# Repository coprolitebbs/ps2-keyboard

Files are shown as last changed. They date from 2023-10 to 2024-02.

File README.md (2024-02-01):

# ps2-keyboard
Самодельная клавиатура с интерфейсом ps/2.
Собрана на Attiny2313A и сдвиговых регистрах 74HC595 и 74HC165.

Прошивка Attiny базируется на библиотеке [ps2dev](https://github.com/Harvie/ps2dev)

Простое описание данных для протокола [PS/2](https://marsohod.org/11-blog/57-ps2proto).

Если что-то не работает, попробуйте старую прошивку из моей же статьи на хабре:
https://habr.com/ru/articles/693784/
Например, эмулятор PS/2 клавиатуры для Спектрума, почему-то, не заводится с последней версией прошивки, но, завелся с версией из статьи.
Собирали на стриме здесь: https://www.youtube.com/watch?v=hVR3ve-gX_8

Прошивка компилируется средой Arduino IDE,

Прошивается с помощью progisp172 программатором через порт "РПрог" для программирования на плате клавиатуры,

Fuse-биты для Attiny2313A: 
Low: E2, High: DF, Ext: FF, Lock: FF

**Имейте ввиду, клавиатура не настраивается под ваш PC или контроллер автоматически,
придется играться с таймингами в исходнике.**

**Для PC используйте значения:**
```
 #define BYTEWAIT 1000
 #define CLK_FULL 40 
 #define CLK_HALF 20
 #define TIMEOUT 30
```

**Для работы с esp32 и библиотекой FabGL используйте**
```
 #define BYTEWAIT 500
 #define CLK_FULL 10 
 #define CLK_HALF 5
 #define TIMEOUT 50
```

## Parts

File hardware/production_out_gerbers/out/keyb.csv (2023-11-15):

Id | Designator | Footprint | Quantity | Designation | Supplier and ref
1 | SW23 | SW_PUSH_KEYB_6mm_H4.3mm | 1 | 9 (
2 | SW18 | SW_PUSH_KEYB_6mm_H4.3mm | 1 | 4 $ ;
3 | SW34 | SW_PUSH_KEYB_6mm_H4.3mm | 1 | + =
4 | SW68 | SW_PUSH_KEYB_6mm_H4.3mm | 1 | X Ч
5 | R11,R13,R10,R7,R8,R19,R20,R15,R14,R6,R18,R17,R12,R5,R9,R16 | R_Axial_DIN0204_L3.6mm_D1.6mm_P7.62mm_Horizontal | 16 | 220
6 | SW19 | SW_PUSH_KEYB_6mm_H4.3mm | 1 | 5 %
7 | SW20 | SW_PUSH_KEYB_6mm_H4.3mm | 1 | 6 ^ :
8 | SW76 | SW_PUSH_KEYB_6mm_H4.3mm | 1 | / ? .
9 | SW12 | SW_PUSH_KEYB_6mm_H4.3mm | 1 | Ф8
10 | SW82,SW78 | SW_PUSH_KEYB_6mm_H4.3mm | 2 | КТРЛ
11 | SW46 | SW_PUSH_KEYB_6mm_H4.3mm | 1 | Y Н
12 | SW67 | SW_PUSH_KEYB_6mm_H4.3mm | 1 | Z Я
13 | SW43 | SW_PUSH_KEYB_6mm_H4.3mm | 1 | ПЕЧАТЬ
14 | R2,R3 | R_Axial_DIN0204_L3.6mm_D1.6mm_P7.62mm_Horizontal | 2 | 1K
15 | SW70 | SW_PUSH_KEYB_6mm_H4.3mm | 1 | V М
16 | SW56 | SW_PUSH_KEYB_6mm_H4.3mm | 1 | S Ы
17 | SW72 | SW_PUSH_KEYB_6mm_H4.3mm | 1 | N Т
18 | SW14 | SW_PUSH_KEYB_6mm_H4.3mm | 1 | Ф10
19 | SW28 | SW_PUSH_KEYB_6mm_H4.3mm | 1 | ВПРАВО
20 | SW60 | SW_PUSH_KEYB_6mm_H4.3mm | 1 | H Р
21 | SW77 | SW_PUSH_KEYB_6mm_H4.3mm | 1 | RSHIFT
22 | SW73 | SW_PUSH_KEYB_6mm_H4.3mm | 1 | M Ь
23 | SW83 | SW_PUSH_KEYB_6mm_H4.3mm | 1 | ПАУЗА
24 | SW65 | SW_PUSH_KEYB_6mm_H4.3mm | 1 | ' Э"
25 | SW79,SW81 | SW_PUSH_KEYB_6mm_H4.3mm | 2 | АЛЬТ
26 | D1 | LED_D3.0mm | 1 | Св.1
27 | SW75 | SW_PUSH_KEYB_6mm_H4.3mm | 1 | > . Ю
28 | SW74 | SW_PUSH_KEYB_6mm_H4.3mm | 1 | < , Б
29 | SW36 | SW_PUSH_KEYB_6mm_H4.3mm | 1 | УДАЛ
30 | SW48 | SW_PUSH_KEYB_6mm_H4.3mm | 1 | I Ш
31 | SW55 | SW_PUSH_KEYB_6mm_H4.3mm | 1 | A Ф
32 | SW6 | SW_PUSH_KEYB_6mm_H4.3mm | 1 | ` ~ Ё
33 | SW30 | SW_PUSH_KEYB_6mm_H4.3mm | 1 | НАЗАД
34 | SW47 | SW_PUSH_KEYB_6mm_H4.3mm | 1 | U Г
35 | SW71 | SW_PUSH_KEYB_6mm_H4.3mm | 1 | B И
36 | J2 | PinSocket_2x03_P2.54mm_Vertical_ICSP | 1 | ICSP
37 | SW11 | SW_PUSH_KEYB_6mm_H4.3mm | 1 | Ф7
38 | SW64 | SW_PUSH_KEYB_6mm_H4.3mm | 1 | : ; Ж
39 | SW7 | SW_PUSH_KEYB_6mm_H4.3mm | 1 | 1 !
40 | SW26 | SW_PUSH_KEYB_6mm_H4.3mm | 1 | ВНИЗ
41 | SW15 | SW_PUSH_KEYB_6mm_H4.3mm | 1 | Ф11
42 | SW22 | SW_PUSH_KEYB_6mm_H4.3mm | 1 | 8 *
43 | SW45 | SW_PUSH_KEYB_6mm_H4.3mm | 1 | T Е
44 | SW32 | SW_PUSH_KEYB_6mm_H4.3mm | 1 | УД. ВП.
45 | SW44 | SW_PUSH_KEYB_6mm_H4.3mm | 1 | R К
46 | RN1 | R_Array_SIP9 | 1 | 10K
47 | SW39 | SW_PUSH_KEYB_6mm_H4.3mm | 1 | W Ц
48 | U3 | DIP-16_W7.62mm_Socket | 1 | KP1564ИP52- 2
49 | SW5 | SW_PUSH_KEYB_6mm_H4.3mm | 1 | Ф4
50 | U1 | DIP-20_W7.62mm_Socket | 1 | ATtiny2313-20P
51 | U2 | DIP-16_W7.62mm_Socket | 1 | KP1564ИP52 - 1
52 | SW27 | SW_PUSH_KEYB_6mm_H4.3mm | 1 | ВЛЕВО
53 | SW63 | SW_PUSH_KEYB_6mm_H4.3mm | 1 | L Д
54 | SW58 | SW_PUSH_KEYB_6mm_H4.3mm | 1 | F А
55 | SW31 | SW_PUSH_KEYB_6mm_H4.3mm | 1 | СТР ВНИЗ
56 | SW41 | SW_PUSH_KEYB_6mm_H4.3mm | 1 | В КОНЕЦ
57 | J1 | PinSocket_1x04_P2.54mm_Vertical | 1 | PS/2
58 | SW51 | SW_PUSH_KEYB_6mm_H4.3mm | 1 | [ X {
59 | SW25 | SW_PUSH_KEYB_6mm_H4.3mm | 1 | ВВЕРХ
60 | SW10 | SW_PUSH_KEYB_6mm_H4.3mm | 1 | Ф6
61 | SW35 | SW_PUSH_KEYB_6mm_H4.3mm | 1 | \
62 | SW50 | SW_PUSH_KEYB_6mm_H4.3mm | 1 | P З
63 | SW57 | SW_PUSH_KEYB_6mm_H4.3mm | 1 | D В
64 | U4 | DIP-16_W7.62mm_Socket | 1 | KP1564ИP9
65 | SW16 | SW_PUSH_KEYB_6mm_H4.3mm | 1 | Ф12
66 | SW52 | SW_PUSH_KEYB_6mm_H4.3mm | 1 | ] Ъ }
67 | SW66 | SW_PUSH_KEYB_6mm_H4.3mm | 1 | LSHIFT
68 | SW9 | SW_PUSH_KEYB_6mm_H4.3mm | 1 | Ф5
69 | SW3 | SW_PUSH_KEYB_6mm_H4.3mm | 1 | Ф2
70 | SW17 | SW_PUSH_KEYB_6mm_H4.3mm | 1 | 3 #
71 | SW13 | SW_PUSH_KEYB_6mm_H4.3mm | 1 | Ф9
72 | SW61 | SW_PUSH_KEYB_6mm_H4.3mm | 1 | J О
73 | SW54 | SW_PUSH_KEYB_6mm_H4.3mm | 1 | ВЕРХРег
74 | R4,R1 | R_Axial_DIN0204_L3.6mm_D1.6mm_P7.62mm_Horizontal | 2 | 10K
75 | SW33 | SW_PUSH_KEYB_6mm_H4.3mm | 1 | - _
76 | SW37 | SW_PUSH_KEYB_6mm_H4.3mm | 1 | ТАБ
77 | C1 | C_Disc_D5.0mm_W2.5mm_P2.50mm | 1 | 0.5Mф
78 | SW59 | SW_PUSH_KEYB_6mm_H4.3mm | 1 | G П
79 | SW24 | SW_PUSH_KEYB_6mm_H4.3mm | 1 | 0 )
80 | SW2 | SW_PUSH_KEYB_6mm_H4.3mm | 1 | Ф1
81 | SW62 | SW_PUSH_KEYB_6mm_H4.3mm | 1 | K Л
82 | SW29 | SW_PUSH_KEYB_6mm_H4.3mm | 1 | ВСТВ
83 | SW42 | SW_PUSH_KEYB_6mm_H4.3mm | 1 | СТР ВВЕРХ
84 | SW84,SW80 | SW_PUSH_KEYB_6mm_H4.3mm | 2 | ПРОБЕЛ
85 | SW49 | SW_PUSH_KEYB_6mm_H4.3mm | 1 | O Щ
86 | SW40 | SW_PUSH_KEYB_6mm_H4.3mm | 1 | E У
87 | D2 | LED_D3.0mm | 1 | Св.2
88 | SW1 | SW_PUSH_KEYB_6mm_H4.3mm | 1 | ОТМ
89 | SW4 | SW_PUSH_KEYB_6mm_H4.3mm | 1 | Ф3
90 | SW53 | SW_PUSH_KEYB_6mm_H4.3mm | 1 | ВВОД
91 | SW8 | SW_PUSH_KEYB_6mm_H4.3mm | 1 | 2 @ ";;; 92;SW38" | SW_PUSH_KEYB_6mm_H4.3mm | 1 | Q Й
93 | SW21 | SW_PUSH_KEYB_6mm_H4.3mm | 1 | 7 & ?
94 | SW69 | SW_PUSH_KEYB_6mm_H4.3mm | 1 | C

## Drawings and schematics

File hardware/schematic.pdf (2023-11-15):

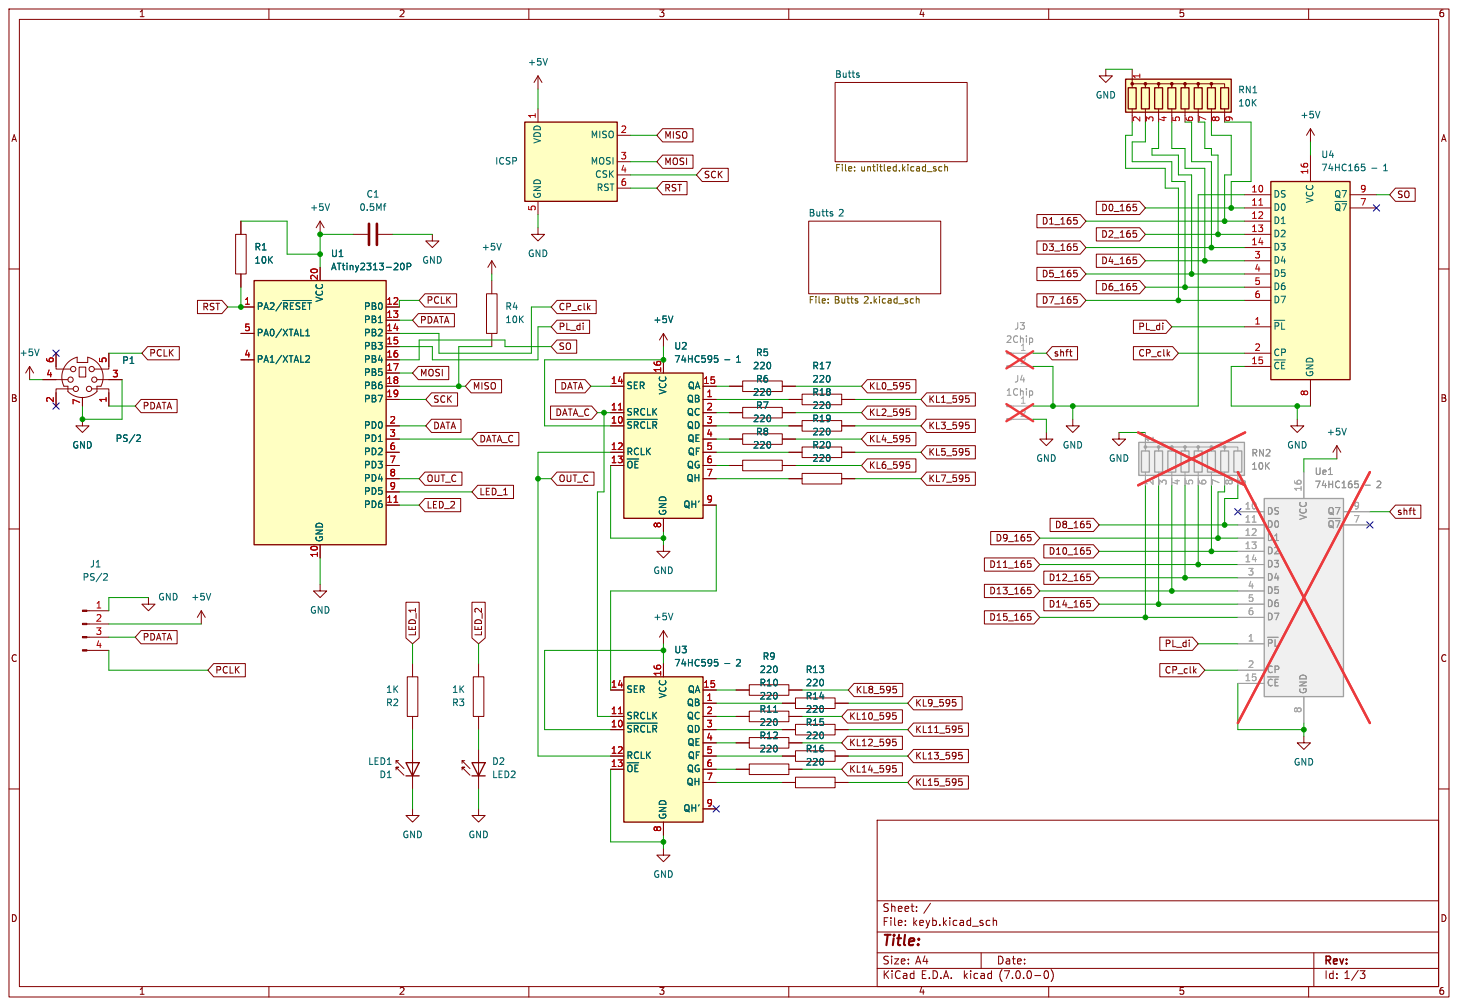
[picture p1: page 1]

Butts 2 File: Butts 2.kicad_sch Butts File: untitled.kicad_sch R1

1 MISO 2 MOSI 3 CSK 4 GND

7 P1 PS/2 PA2/~{RESET} 1 GND 10 PD6 11 PB0 12 PB1 13 PB2 14 PB3 15 PB4 16 PB5 17 PB6 18 PB7 19 PD0 2 VCC 20 PD1 3 PA1/XTAL2 4 PA0/XTAL1 5 PD2 6 PD3 7 PD4 8 PD5 9 U1ATtiny2313-20P

Id: 1/3 Title: File: keyb.kicad_sch Sheet: /

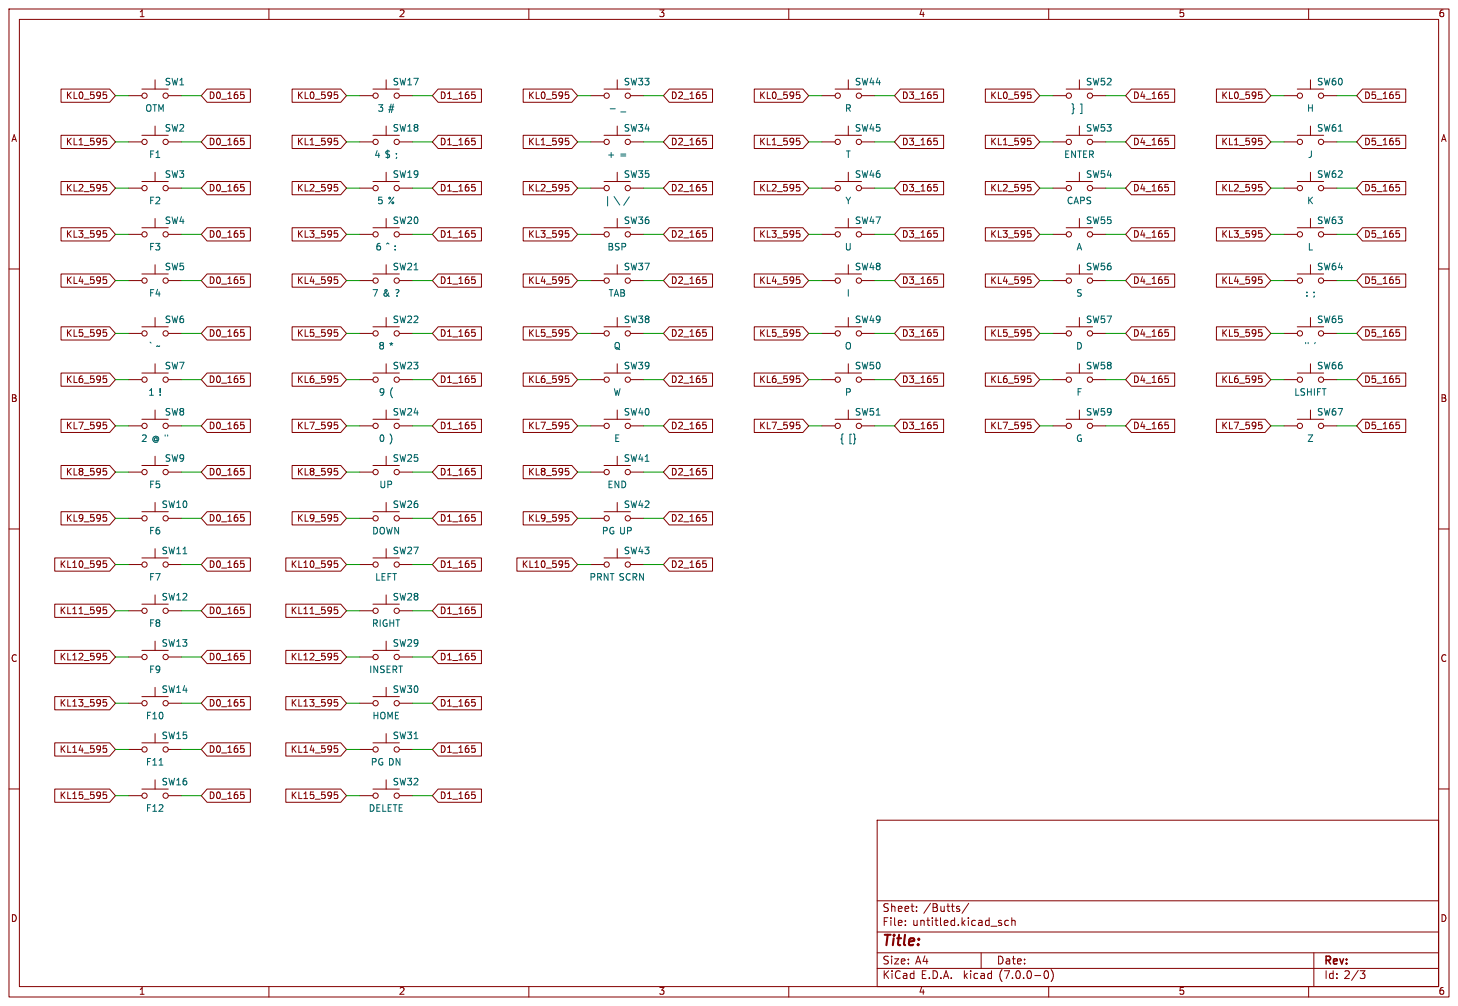
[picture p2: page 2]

Id: 2/3 Title: File: untitled.kicad_sch Sheet: /Butts/

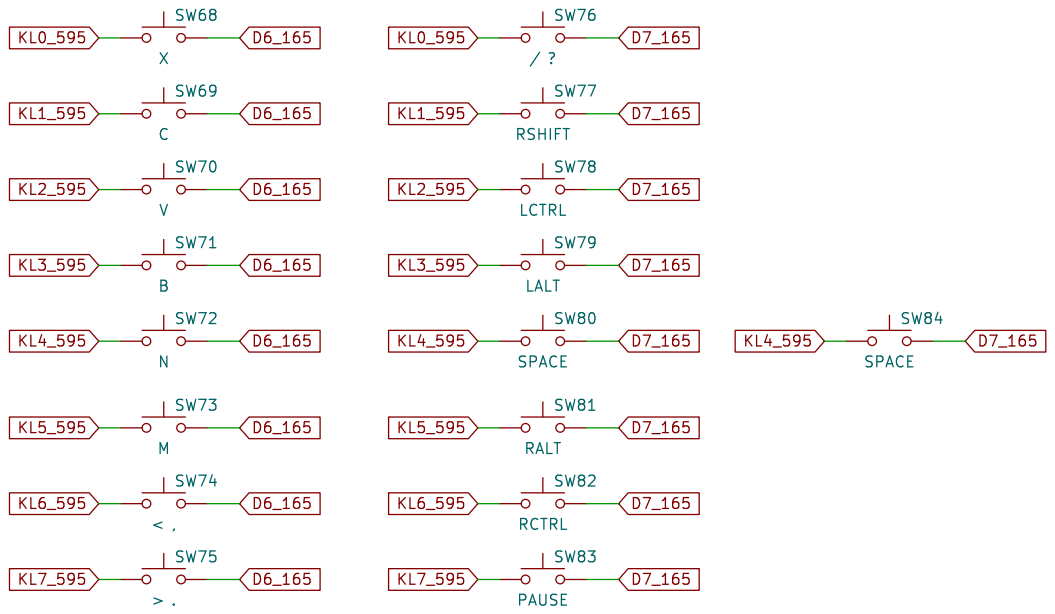
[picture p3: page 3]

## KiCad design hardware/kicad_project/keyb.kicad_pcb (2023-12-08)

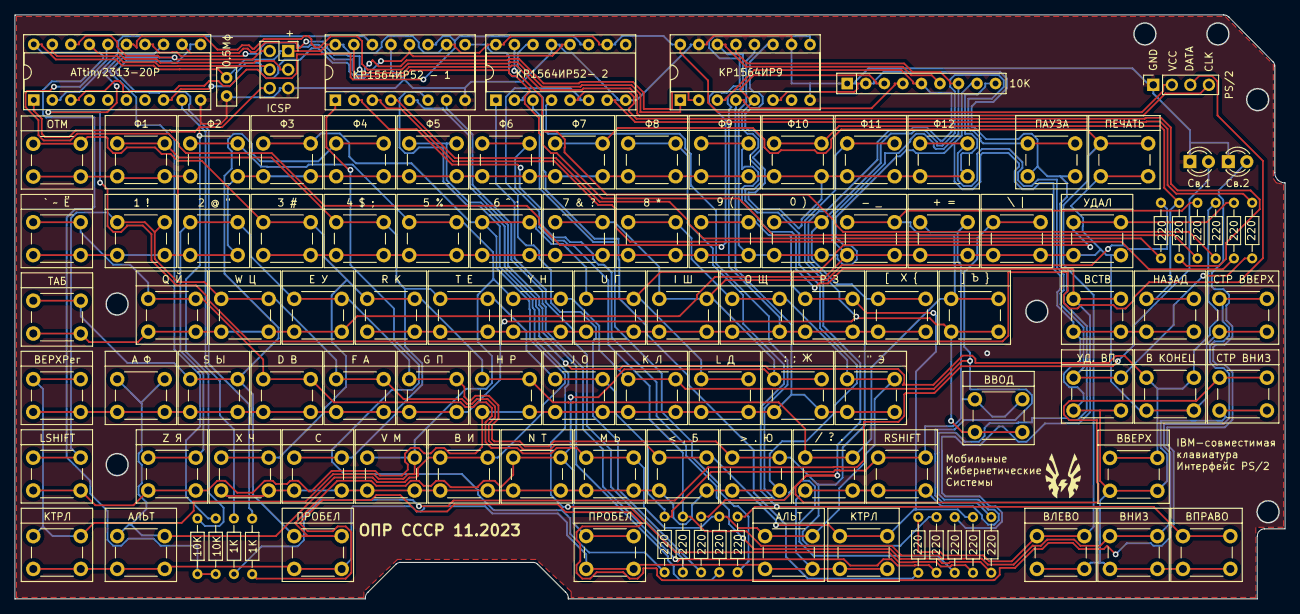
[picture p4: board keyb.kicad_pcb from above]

Board: 2 copper layers, 174.0 x 80.0 mm, 114 parts (0 on the bottom side), 59 nets.

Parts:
C1: 0.5Mф; C_Disc_D5.0mm_W2.5mm_P2.50mm
D1: Св.1; LED_D3.0mm
D2: Св.2; LED_D3.0mm
J1: PS/2; PinSocket_1x04_P2.54mm_Vertical
J2: ICSP; PinSocket_2x03_P2.54mm_Vertical_ICSP
R1, R4: 10K; R_Axial_DIN0204_L3.6mm_D1.6mm_P7.62mm_Horizontal
R2, R3: 1K; R_Axial_DIN0204_L3.6mm_D1.6mm_P7.62mm_Horizontal
R5, R6, R7, R8, R9, R10, R11, R12, R13, R14, R15, R16, R17, R18, R19, R20: 220; R_Axial_DIN0204_L3.6mm_D1.6mm_P7.62mm_Horizontal
RN1: 10K; R_Array_SIP9
SW1: ОТМ; SW_PUSH_KEYB_6mm_H4.3mm
SW2: Ф1; SW_PUSH_KEYB_6mm_H4.3mm
SW3: Ф2; SW_PUSH_KEYB_6mm_H4.3mm
SW4: Ф3; SW_PUSH_KEYB_6mm_H4.3mm
SW5: Ф4; SW_PUSH_KEYB_6mm_H4.3mm
SW6: ` ~ Ё; SW_PUSH_KEYB_6mm_H4.3mm
SW7: 1 !; SW_PUSH_KEYB_6mm_H4.3mm
SW8: 2 @ "; SW_PUSH_KEYB_6mm_H4.3mm
SW9: Ф5; SW_PUSH_KEYB_6mm_H4.3mm
SW10: Ф6; SW_PUSH_KEYB_6mm_H4.3mm
SW11: Ф7; SW_PUSH_KEYB_6mm_H4.3mm
SW12: Ф8; SW_PUSH_KEYB_6mm_H4.3mm
SW13: Ф9; SW_PUSH_KEYB_6mm_H4.3mm
SW14: Ф10; SW_PUSH_KEYB_6mm_H4.3mm
SW15: Ф11; SW_PUSH_KEYB_6mm_H4.3mm
SW16: Ф12; SW_PUSH_KEYB_6mm_H4.3mm
SW17: 3 #; SW_PUSH_KEYB_6mm_H4.3mm
SW18: 4 $ ;; SW_PUSH_KEYB_6mm_H4.3mm
SW19: 5 %; SW_PUSH_KEYB_6mm_H4.3mm
SW20: 6 ^ :; SW_PUSH_KEYB_6mm_H4.3mm
SW21: 7 & ?; SW_PUSH_KEYB_6mm_H4.3mm
SW22: 8 *; SW_PUSH_KEYB_6mm_H4.3mm
SW23: 9 (; SW_PUSH_KEYB_6mm_H4.3mm
SW24: 0 ); SW_PUSH_KEYB_6mm_H4.3mm
SW25: ВВЕРХ; SW_PUSH_KEYB_6mm_H4.3mm
SW26: ВНИЗ; SW_PUSH_KEYB_6mm_H4.3mm
SW27: ВЛЕВО; SW_PUSH_KEYB_6mm_H4.3mm
SW28: ВПРАВО; SW_PUSH_KEYB_6mm_H4.3mm
SW29: ВСТВ; SW_PUSH_KEYB_6mm_H4.3mm
SW30: НАЗАД; SW_PUSH_KEYB_6mm_H4.3mm
SW31: СТР ВНИЗ; SW_PUSH_KEYB_6mm_H4.3mm
SW32: УД. ВП.; SW_PUSH_KEYB_6mm_H4.3mm
SW33: - _; SW_PUSH_KEYB_6mm_H4.3mm
SW34: + =; SW_PUSH_KEYB_6mm_H4.3mm
SW35: \ |; SW_PUSH_KEYB_6mm_H4.3mm
SW36: УДАЛ; SW_PUSH_KEYB_6mm_H4.3mm
SW37: ТАБ; SW_PUSH_KEYB_6mm_H4.3mm
SW38: Q Й; SW_PUSH_KEYB_6mm_H4.3mm
SW39: W Ц; SW_PUSH_KEYB_6mm_H4.3mm
SW40: E У; SW_PUSH_KEYB_6mm_H4.3mm
SW41: В КОНЕЦ; SW_PUSH_KEYB_6mm_H4.3mm
SW42: СТР ВВЕРХ; SW_PUSH_KEYB_6mm_H4.3mm
SW43: ПЕЧАТЬ; SW_PUSH_KEYB_6mm_H4.3mm
SW44: R К; SW_PUSH_KEYB_6mm_H4.3mm
SW45: T Е; SW_PUSH_KEYB_6mm_H4.3mm
SW46: Y Н; SW_PUSH_KEYB_6mm_H4.3mm
SW47: U Г; SW_PUSH_KEYB_6mm_H4.3mm
SW48: I Ш; SW_PUSH_KEYB_6mm_H4.3mm
SW49: O Щ; SW_PUSH_KEYB_6mm_H4.3mm
SW50: P З; SW_PUSH_KEYB_6mm_H4.3mm
SW51: [ X {; SW_PUSH_KEYB_6mm_H4.3mm
SW52: ] Ъ }; SW_PUSH_KEYB_6mm_H4.3mm
SW53: ВВОД; SW_PUSH_KEYB_6mm_H4.3mm
SW54: ВЕРХРег; SW_PUSH_KEYB_6mm_H4.3mm
SW55: A Ф; SW_PUSH_KEYB_6mm_H4.3mm
SW56: S Ы; SW_PUSH_KEYB_6mm_H4.3mm
SW57: D В; SW_PUSH_KEYB_6mm_H4.3mm
SW58: F А; SW_PUSH_KEYB_6mm_H4.3mm
SW59: G П; SW_PUSH_KEYB_6mm_H4.3mm
SW60: H Р; SW_PUSH_KEYB_6mm_H4.3mm
SW61: J О; SW_PUSH_KEYB_6mm_H4.3mm
SW62: K Л; SW_PUSH_KEYB_6mm_H4.3mm
SW63: L Д; SW_PUSH_KEYB_6mm_H4.3mm
SW64: : ; Ж; SW_PUSH_KEYB_6mm_H4.3mm
SW65: ' " Э; SW_PUSH_KEYB_6mm_H4.3mm
SW66: LSHIFT; SW_PUSH_KEYB_6mm_H4.3mm
SW67: Z Я; SW_PUSH_KEYB_6mm_H4.3mm
SW68: X Ч; SW_PUSH_KEYB_6mm_H4.3mm
SW69: C; SW_PUSH_KEYB_6mm_H4.3mm
SW70: V М; SW_PUSH_KEYB_6mm_H4.3mm
SW71: B И; SW_PUSH_KEYB_6mm_H4.3mm
SW72: N Т; SW_PUSH_KEYB_6mm_H4.3mm
SW73: M Ь; SW_PUSH_KEYB_6mm_H4.3mm
SW74: < , Б; SW_PUSH_KEYB_6mm_H4.3mm
SW75: > . Ю; SW_PUSH_KEYB_6mm_H4.3mm
SW76: / ? .; SW_PUSH_KEYB_6mm_H4.3mm
SW77: RSHIFT; SW_PUSH_KEYB_6mm_H4.3mm
SW78, SW82: КТРЛ; SW_PUSH_KEYB_6mm_H4.3mm
SW79, SW81: АЛЬТ; SW_PUSH_KEYB_6mm_H4.3mm
SW80, SW84: ПРОБЕЛ; SW_PUSH_KEYB_6mm_H4.3mm
SW83: ПАУЗА; SW_PUSH_KEYB_6mm_H4.3mm
U1: ATtiny2313-20P; DIP-20_W7.62mm_Socket
U2: KP1564ИP52 - 1; DIP-16_W7.62mm_Socket
U3: KP1564ИP52- 2; DIP-16_W7.62mm_Socket
U4: KP1564ИP9; DIP-16_W7.62mm_Socket

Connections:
+5V: C1.2, J1.2, J2.1 (VDD), R1.1, R4.1, U1.20 (VCC), U2.10 (~SRCLR), U2.16 (VCC), U3.10 (~SRCLR), U3.16 (VCC), U4.16 (VCC)
CP_clk: U1.14 (PB2), U4.2 (CP)
D0_165: RN1.9 (R8), SW1.2, SW2.2, SW3.2, SW4.2, SW5.2, SW6.2, SW7.2, SW8.2, SW9.2, SW10.2, SW11.2, SW12.2, SW13.2, SW14.2, SW15.2, SW16.2, U4.11 (D0)
D1_165: RN1.8 (R7), SW17.2, SW18.2, SW19.2, SW20.2, SW21.2, SW22.2, SW23.2, SW24.2, SW25.2, SW26.2, SW27.2, SW28.2, SW29.2, SW30.2, SW31.2, SW32.2, U4.12 (D1)
D2_165: RN1.7 (R6), SW33.2, SW34.2, SW35.2, SW36.2, SW37.2, SW38.2, SW39.2, SW40.2, SW41.2, SW42.2, SW43.2, U4.13 (D2)
D3_165: RN1.6 (R5), SW44.2, SW45.2, SW46.2, SW47.2, SW48.2, SW49.2, SW50.2, SW51.2, U4.14 (D3)
D4_165: RN1.5 (R4), SW52.2, SW53.2, SW54.2, SW55.2, SW56.2, SW57.2, SW58.2, SW59.2, U4.3 (D4)
D5_165: RN1.4 (R3), SW60.2, SW61.2, SW62.2, SW63.2, SW64.2, SW65.2, SW66.2, SW67.2, U4.4 (D5)
D6_165: RN1.3 (R2), SW68.2, SW69.2, SW70.2, SW71.2, SW72.2, SW73.2, SW74.2, SW75.2, U4.5 (D6)
D7_165: RN1.2 (R1), SW76.2, SW77.2, SW78.2, SW79.2, SW80.2, SW81.2, SW82.2, SW83.2, SW84.2, U4.6 (D7)
DATA: U1.2 (PD0), U2.14 (SER)
DATA_C: U1.3 (PD1), U2.11 (SRCLK), U3.11 (SRCLK)
GND: C1.1, D1.1 (K), D2.1 (K), J1.1, J2.5 (GND), RN1.1 (common), U1.10 (GND), U2.8 (GND), U2.13 (~OE), U3.8 (GND), U3.13 (~OE), U4.8 (GND), U4.10 (DS), U4.15 (~CE)
KL0_595: R5.2, SW1.1, SW17.1, SW33.1, SW44.1, SW52.1, SW60.1, SW68.1, SW76.1
KL1_595: R17.2, SW2.1, SW18.1, SW34.1, SW45.1, SW53.1, SW61.1, SW69.1, SW77.1
KL2_595: R6.2, SW3.1, SW19.1, SW35.1, SW46.1, SW54.1, SW62.1, SW70.1, SW78.1
KL3_595: R18.2, SW4.1, SW20.1, SW36.1, SW47.1, SW55.1, SW63.1, SW71.1, SW79.1
KL4_595: R7.2, SW5.1, SW21.1, SW37.1, SW48.1, SW56.1, SW64.1, SW72.1, SW80.1, SW84.1
KL5_595: R19.2, SW6.1, SW22.1, SW38.1, SW49.1, SW57.1, SW65.1, SW73.1, SW81.1
KL6_595: R8.2, SW7.1, SW23.1, SW39.1, SW50.1, SW58.1, SW66.1, SW74.1, SW82.1
KL7_595: R20.2, SW8.1, SW24.1, SW40.1, SW51.1, SW59.1, SW67.1, SW75.1, SW83.1
KL8_595: R9.2, SW9.1, SW25.1, SW41.1
KL9_595: R13.2, SW10.1, SW26.1, SW42.1
KL10_595: R10.2, SW11.1, SW27.1, SW43.1
KL11_595: R14.2, SW12.1, SW28.1
KL12_595: R11.2, SW13.1, SW29.1
KL13_595: R15.2, SW14.1, SW30.1
KL14_595: R12.2, SW15.1, SW31.1
KL15_595: R16.2, SW16.1, SW32.1
LED_1: R2.2, U1.9 (PD5)
LED_2: R3.2, U1.11 (PD6)
MISO: J2.2 (MISO), R4.2, U1.18 (PB6)
MOSI: J2.3 (MOSI), U1.17 (PB5)
unnamed: D1.2 (A), R2.1
unnamed: D2.2 (A), R3.1
unnamed: R5.1, U2.15 (QA)
unnamed: R17.1, U2.1 (QB)
unnamed: R6.1, U2.2 (QC)
unnamed: R18.1, U2.3 (QD)
unnamed: R7.1, U2.4 (QE)
unnamed: R19.1, U2.5 (QF)
unnamed: R8.1, U2.6 (QG)
unnamed: U2.9 (QH'), U3.14 (SER)
unnamed: R20.1, U2.7 (QH)
unnamed: R9.1, U3.15 (QA)
unnamed: R13.1, U3.1 (QB)
unnamed: R10.1, U3.2 (QC)
unnamed: R14.1, U3.3 (QD)
unnamed: R11.1, U3.4 (QE)
unnamed: R15.1, U3.5 (QF)
unnamed: R12.1, U3.6 (QG)
unnamed: R16.1, U3.7 (QH)
OUT_C: U1.8 (PD4), U2.12 (RCLK), U3.12 (RCLK)
PCLK: J1.4, U1.12 (PB0)
PDATA: J1.3, U1.13 (PB1)
PL_di: U1.15 (PB3), U4.1 (~PL)
RST: J2.6 (RST), R1.2, U1.1 (PA2/~RESET)
SCK: J2.4 (CSK), U1.19 (PB7)
SO: U1.16 (PB4), U4.9 (Q7)

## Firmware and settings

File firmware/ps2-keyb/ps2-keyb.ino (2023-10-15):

// https://github.com/Harvie/ps2dev/
// https://codeandlife.com/2013/06/28/minimal-ps2-keyboard-on-attiny2313/

#include <avr/io.h> //подключаем библиотеку аппаратных описаний
#include <util/delay.h> //поключаем библиотеку задержек

//#define KEYMAPSIZE 256

//Битовый массив нажатых клавиш. Если клавиша нажата, то в слове по номеру строки бит по номеру столбца будет установлен
word pr[16] = {0, 0, 0, 0, 0, 0, 0, 0, 0, 0, 0, 0, 0, 0, 0, 0};

//Для использования 1 чипа 165 оставить значение 8
//Для двух чипов - 16
#define CHIP_J_COUNT 8

//Массив скан-кодов клавиш
const unsigned char keymap[] PROGMEM =
{
  0x76, 0x26, 0x4E, 0x2D, 0x5B, 0x33, 0x22, 0x4A,   0x29, 0x29, 0x29, 0x29, 0x29, 0x29, 0x29, 0x29,
  0x05, 0x25, 0x55, 0x2C, 0x5A, 0x3B, 0x21, 0x59,   0x29, 0x29, 0x29, 0x29, 0x29, 0x29, 0x29, 0x29,
  0x06, 0x2E, 0x5D, 0x35, 0x58, 0x42, 0x2A, 0x14,   0x29, 0x29, 0x29, 0x29, 0x29, 0x29, 0x29, 0x29,
  0x04, 0x36, 0x66, 0x3C, 0x1C, 0x4B, 0x32, 0x11,   0x29, 0x29, 0x29, 0x29, 0x29, 0x29, 0x29, 0x29,
  0x0C, 0x3D, 0x0D, 0x43, 0x1B, 0x4C, 0x31, 0x29,   0x29, 0x29, 0x29, 0x29, 0x29, 0x29, 0x29, 0x29,
  0x0E, 0x3E, 0x15, 0x44, 0x23, 0x41, 0x3A, 0xE0,   0x29, 0x29, 0x29, 0x29, 0x29, 0x29, 0x29, 0x29,
  0x16, 0x46, 0x1D, 0x4D, 0x2B, 0x12, 0x41, 0xE1,   0x29, 0x29, 0x29, 0x29, 0x29, 0x29, 0x29, 0x29,
  0x1E, 0x45, 0x24, 0x54, 0x34, 0x1A, 0x49, 0xE2,   0x29, 0x29, 0x29, 0x29, 0x29, 0x29, 0x29, 0x29,

  0x03, 0xE3, 0xE4, 0x29, 0x29, 0x29, 0x29, 0x29,   0x29, 0x29, 0x29, 0x29, 0x29, 0x29, 0x29, 0x29,
  0x0B, 0xE5, 0xE6, 0x29, 0x29, 0x29, 0x29, 0x29,   0x29, 0x29, 0x29, 0x29, 0x29, 0x29, 0x29, 0x29,
  0x83, 0xE7, 0xE8, 0x29, 0x29, 0x29, 0x29, 0x29,   0x29, 0x29, 0x29, 0x29, 0x29, 0x29, 0x29, 0x29,
  0x0A, 0xE9, 0x29, 0x29, 0x29, 0x29, 0x29, 0x29,   0x29, 0x29, 0x29, 0x29, 0x29, 0x29, 0x29, 0x29,
  0x01, 0xEA, 0x29, 0x29, 0x29, 0x29, 0x29, 0x29,   0x29, 0x29, 0x29, 0x29, 0x29, 0x29, 0x29, 0x29,
  0x09, 0xEB, 0x29, 0x29, 0x29, 0x29, 0x29, 0x29,   0x29, 0x29, 0x29, 0x29, 0x29, 0x29, 0x29, 0x29,
  0x78, 0xEC, 0x29, 0x29, 0x29, 0x29, 0x29, 0x29,   0x29, 0x29, 0x29, 0x29, 0x29, 0x29, 0x29, 0x29,
  0x07, 0xED, 0x29, 0x29, 0x29, 0x29, 0x29, 0x29,   0x29, 0x29, 0x29, 0x29, 0x29, 0x29, 0x29, 0x29
};

//Длина максимальной последовательности расширенных кодов для клавиши
#define EXT_K_SIZE 8

//Массив клавиш с расширенными кодами.
//Если в массиве основных кодов выше указан код >= E0, то будет выбрана последовательность
//из данного массива с номером (Номер - E0), т.е., код E0 - первая, E1 - вторая, и т.д.
//Коды 0x00 будут игнорироваться
const unsigned char extcodes[]/*14][EXT_K_SIZE]*/ PROGMEM = {
  0xE0, 0x11, 0x00, 0x00, 0x00, 0x00, 0x00, 0x00,   //R ALT  (E0)
  0xE0, 0x14, 0x00, 0x00, 0x00, 0x00, 0x00, 0x00,   //R CTRL (E1)
  0xE1, 0x14, 0x77, 0xE1, 0xF0, 0x14, 0xE0, 0x77,   //PAUSE  (E2)
  0xE0, 0x75, 0x00, 0x00, 0x00, 0x00, 0x00, 0x00,   //UP     (E3)
  0xE0, 0x69, 0x00, 0x00, 0x00, 0x00, 0x00, 0x00,   //END    (E4)
  0xE0, 0x72, 0x00, 0x00, 0x00, 0x00, 0x00, 0x00,   //DOWN   (E5)
  0xE0, 0x7D, 0x00, 0x00, 0x00, 0x00, 0x00, 0x00,   //PG UP  (E6)
  0xE0, 0x6B, 0x00, 0x00, 0x00, 0x00, 0x00, 0x00,   //LEFT   (E7)
  0xE0, 0x12, 0xE0, 0x7C, 0x00, 0x00, 0x00, 0x00,   //PT SCR (E8)
  0xE0, 0x74, 0x00, 0x00, 0x00, 0x00, 0x00, 0x00,   //RIGHT  (E9)
  0xE0, 0x70, 0x00, 0x00, 0x00, 0x00, 0x00, 0x00,   //INS    (EA)
  0xE0, 0x6C, 0x00, 0x00, 0x00, 0x00, 0x00, 0x00,   //HOME   (EB)
  0xE0, 0x7A, 0x00, 0x00, 0x00, 0x00, 0x00, 0x00,   //PG DN  (EC)
  0xE0, 0x71, 0x00, 0x00, 0x00, 0x00, 0x00, 0x00    //DEL    (ED)
};

//То же самое для кодов отпускания клавиш
const unsigned char extcanscodes[]/*14][EXT_K_SIZE]*/ PROGMEM = {
  0xE0, 0xF0, 0x11, 0x00, 0x00, 0x00, 0x00, 0x00,   //R ALT  (E0)
  0xE0, 0xF0, 0x14, 0x00, 0x00, 0x00, 0x00, 0x00,   //R CTRL (E1)
  0x00, 0x00, 0x00, 0x00, 0x00, 0x00, 0x00, 0x00,   //PAUSE  (E2)
  0xE0, 0xF0, 0x75, 0x00, 0x00, 0x00, 0x00, 0x00,   //UP     (E3)
  0xE0, 0xF0, 0x69, 0x00, 0x00, 0x00, 0x00, 0x00,   //END    (E4)
  0xE0, 0xF0, 0x72, 0x00, 0x00, 0x00, 0x00, 0x00,   //DOWN   (E5)
  0xE0, 0xF0, 0x7D, 0x00, 0x00, 0x00, 0x00, 0x00,   //PG UP  (E6)
  0xE0, 0xF0, 0x6B, 0x00, 0x00, 0x00, 0x00, 0x00,   //LEFT   (E7)
  0xE0, 0xF0, 0x7C, 0xE0, 0xF0, 0x12, 0x00, 0x00,   //PT SCR (E8)
  0xE0, 0xF0, 0x74, 0x00, 0x00, 0x00, 0x00, 0x00,   //RIGHT  (E9)
  0xE0, 0xF0, 0x70, 0x00, 0x00, 0x00, 0x00, 0x00,   //INS    (EA)
  0xE0, 0xF0, 0x6C, 0x00, 0x00, 0x00, 0x00, 0x00,   //HOME   (EB)
  0xE0, 0xF0, 0x7A, 0x00, 0x00, 0x00, 0x00, 0x00,   //PG DN  (EC)
  0xE0, 0xF0, 0x71, 0x00, 0x00, 0x00, 0x00, 0x00    //DEL    (ED)
};






//Зададим пины светодиода Св1
#define LED1 7
#define LED1_PORT PORTD
#define LED1_PIN 5

//Зададим пины светодиода Св2
#define LED2 8
#define LED2_PORT PORTD
#define LED2_PIN 6

//Задаем пины для управления PS/2
#define PS2_CLOCK_DDR DDRB
#define PS2_CLOCK_PORT PORTB
#define PS2_CLOCK_PIN 0
#define PS2_CLOCK_INPUT PINB
#define ps2clock 9

#define PS2_DATA_DDR DDRB
#define PS2_DATA_PORT PORTB
#define PS2_DATA_PIN 1
#define PS2_DATA_INPUT PINB
#define ps2data 10

//Задаем пины 74HC595
#define RPORT PORTD
#define RDATA_PORT PORTD
#define RDATA_PIN 0
#define RCLOCK_PORT PORTD
#define RCLOCK_PIN 1
#define RLATCH_PORT PORTD
#define RLATCH_PIN 4
#define RDATA 0
#define RCLOCK 1
#define RLATCH 6

//Задаем пины 74HC165
#define IPORT PORTB
#define IDATA_DDR DDRB
#define IDATA_PORT PORTB
#define IDATA_PIN 4
#define ICLOCK_PORT PORTB
#define ICLOCK_PIN 2
#define ILATCH_PORT PORTB
#define ILATCH_PIN 3
#define IDATA 13
#define ICLOCK 11
#define ILATCH 12

//байт состояния светодиодов
unsigned char leds;

//Установить вывод PS/2 CLOCK в HIGH
static void clockHigh(void) {
  PS2_CLOCK_DDR &= ~_BV(PS2_CLOCK_PIN); // set as input
  PS2_CLOCK_PORT |= _BV(PS2_CLOCK_PIN); // set pullup
}

//Установить вывод PS/2 CLOCK в LOW
static void clockLow(void) {
  PS2_CLOCK_PORT &= ~_BV(PS2_CLOCK_PIN); // zero output value
  PS2_CLOCK_DDR |= _BV(PS2_CLOCK_PIN); // set as output
}

//Установить вывод PS/2 DATA в HIGH
static void dataHigh(void) {
  PS2_DATA_DDR &= ~_BV(PS2_DATA_PIN); // set as input
  PS2_DATA_PORT |= _BV(PS2_DATA_PIN); // set pullup
}

//Установить вывод PS/2 DATA в LOW
static void dataLow(void) {
  PS2_DATA_PORT &= ~_BV(PS2_DATA_PIN); // zero output value
  PS2_DATA_DDR |= _BV(PS2_DATA_PIN); // set as output
}

//Ускоренные процедуры чтения пинов PS/2
#define readClockPin() (PS2_CLOCK_INPUT & (1 << PS2_CLOCK_PIN))
#define readDataPin() (PS2_DATA_INPUT & (1 << PS2_DATA_PIN))
#define readReg165Pin() (PINB & (1 << IDATA_PIN))

//Тайминги ожидания при установке выводов PS/2
#define CLK_FULL 40 // 40+40 us for 12.5 kHz clock
#define CLK_HALF 20
//Таймаут проверки состояния пинов PS/2 при чтении
#define TIMEOUT 30

//Ожидание в мс перед и после отправки байта в порт
#define BYTEWAIT 1000


//Инициализация порта PS/2
void init_ps2() {

  DDRD = (1 << RDATA_PIN) | (1 << RCLOCK_PIN) | (1 << RLATCH_PIN) | (1 << LED1_PIN) | (1 << LED2_PIN);

  //Установим оба диода в LOW
  LED1_PORT &= ~(1 << LED1_PIN);
  LED2_PORT &= ~(1 << LED2_PIN);

  //установим выходы регистра 27HC165
  DDRB |= (1 << ICLOCK_PIN) | (1 << ILATCH_PIN);
  DDRB &= ~(1 << IDATA_PIN);

  //Установим выводы PS/2 CLOCK и DATA в HIGH
  clockHigh();
  dataHigh();


  //Отправим по PS/2 код 0xAA, означающий готовность клавиатуры к работе
  while (keyb_write(0xAA) != 0);
  //  keyb_write(0xAA);
  _delay_us(10);


  //return;
}


//Отдельная процедура - Сделать строб на выводе PS/2 CLOCK
void do_clock_lo_hi() {
  _delay_us(CLK_HALF);
  clockLow(); // start bit
  _delay_us(CLK_FULL);
  clockHigh();
  _delay_us(CLK_HALF);
  //return;
}

//Проверка состояния выводов PS/2 CLOCK и DATA
int keyb_check() {
  return (!readClockPin() || !readDataPin());
}

//Универсальный ответ клавиатуры - подтверждение об успешном приеме
void ack() {
  while (keyb_write(0xFA));
  //keyb_write(0xFA);
  //_delay_us(CLK_HALF);
}



//Считывание с регистра 74HC165
uint16_t shiftIn165()
{
  uint16_t value = 0;

  //Включим-выключим защелку
  ILATCH_PORT &= ~(1 << ILATCH_PIN); //LOW
  ILATCH_PORT |= (1 << ILATCH_PIN);  //HIGH

  //Считаем побитно содержимое регистра
  for (uint8_t i = 0; i < CHIP_J_COUNT; ++i)
  {
    ICLOCK_PORT &= ~(1 << ICLOCK_PIN); //LOW
    value |= bitRead(PINB, IDATA_PIN) << ((CHIP_J_COUNT - 1) - i); //digitalRead(IDATA) << (15 - i);
    ICLOCK_PORT |= (1 << ICLOCK_PIN);  //HIGH
  }

  return value;
}

//Функция чтения данных с порта PS/2
int keyboard_read(unsigned char * value) {
  unsigned int data = 0x00;
  unsigned int bit = 0x01;

  unsigned char calculated_parity = 1;
  unsigned char received_parity = 0;

  unsigned long waiting_since = millis();
  while ((readDataPin()) || (!readClockPin()) /*(digitalRead(ps2data) != LOW) || (digitalRead(ps2clock) != HIGH)*/ ) {
    if ((millis() - waiting_since) > TIMEOUT) return -1;
  }

  do_clock_lo_hi();

  while (bit < 0x0100) {
    if (readDataPin()/*digitalRead(ps2data) == HIGH*/) {
      data = data | bit;
      calculated_parity = calculated_parity ^ 1;
    } else {
      calculated_parity = calculated_parity ^ 0;
    }
    bit = bit << 1;
    do_clock_lo_hi();
  }

  // parity bit
  if (readDataPin()/*digitalRead(ps2data) == HIGH*/) {
    received_parity = 1;
  }

  do_clock_lo_hi();

  _delay_us(CLK_HALF);
  dataLow();
  clockLow();
  _delay_us(CLK_FULL);
  clockHigh();
  _delay_us(CLK_HALF);
  dataHigh();

  *value = data & 0x00FF;

  if (received_parity == calculated_parity) {
    return 0;
  } else {
    return -2;
  }
}



//Запись байта в PS/2
int keyb_write(unsigned char data)
{
  _delay_us(BYTEWAIT);

  unsigned char val;
  unsigned char received_parity = 1;

  if (/*digitalRead(ps2clock) == LOW*/ !readClockPin()) {
    return -1;
  }

  if (/*digitalRead(ps2data) == LOW*/ !readDataPin()) {
    return -2;
  }

  dataLow();

  do_clock_lo_hi();

  for (val = 0; val < 8; val++)
  {
    if (data & 0x01)
    {
      dataHigh();
    } else {
      dataLow();
    }

    do_clock_lo_hi();

    received_parity = (!(received_parity % 2)); //received_parity ^ (data & 0x01);
    data = data >> 1;
  }
  // parity bit
  if (received_parity)
  {
    dataHigh();
  } else {
    dataLow();
  }
  do_clock_lo_hi();

  // stop bit
  dataHigh();
  do_clock_lo_hi();

  _delay_us(BYTEWAIT);

  return 0;
}

// грязный хак для выполнения ресета контроллера в функции вызова ресета клавиатуры
void (*reset)(void) = (void*)0;




int keyboard_reply(unsigned char cmd, unsigned char *leds) {

  unsigned char val;

// ряд не особо нужных кодов закомментирован и не используется
// в следствие нехватки памяти для компилированного кода.
// Параметры таймингов клавиатуры приходится изменять буквально
// перекомпиляцие и перепрошивкой, увы.

  switch (cmd) {
    case 0xFF: //reset
      ack();
      reset();
      break; //Не знаю, как тут изящно завершить
    case 0xFE: //resend
    //      ack();
    //      break;
    //case 0xFA: //Set all keys to typematic/autorepeat
    //      ack();
    //      break;
    //case 0xF9: //Set all keys to make only
    //      ack();
    //      break;
    //case 0xF8:
    //case 0xF7:
    //case 0xF6: //set defaults
    //      ack();
    //      break;
    //case 0xF5: //disable data reporting
    //FM
    //enabled = 0;
    //      ack();
    //      break;
    //case 0xF4: //enable data reporting
    //FM
    //enabled = 1;
    //ack();
    //break;
    case 0xF3: //set typematic rate
      ack();
      /*if (!keyboard_read(&val)) {
        ack(); //do nothing with the rate
        } else {
        if(bitRead(val,5)==1){
          if(bitRead(val,6)==1){
            waittime = 1000;
          } else {
            waittime = 750;
          }
        } else {
          if(bitRead(val,6)==1){
            waittime = 500;
          } else {
            waittime = 250;
          }
        }
        val = (val << 4) >> 4;

        }*/
      break;
    case 0xF2: //Сообщить device id
      ack();
      //0xAB83 - идентификатор оборудования стандартной клавиатуры ps/2
      while (keyb_write(0xAB) != 0);

      //_delay_us(CLK_HALF);
      while (keyb_write(0x83) != 0);
      //digitalWrite(LED1, HIGH);
      //_delay_us(80);
      //digitalWrite(LED1, LOW);
      break;
    case 0xF0: //set scan code set
      ack();
      if (!keyboard_read(&val)) ack(); //do nothing with the rate
      break;
    case 0xEE: //echo
      //ack();
      keyb_write(0xEE);
      break;
    case 0xED: //set/reset LEDs
      ack();
      if (!keyboard_read(leds)) ack(); //do nothing with the rate
      return 1;
      break;
      /* default:
         LED2_PORT |= (1 << LED2_PIN);
         _delay_us(100);
         LED2_PORT &= ~(1 << LED2_PIN);*/
  }
  return 0;
}




int keyboard_read_check(unsigned char *leds) {
  unsigned char c;

  if ( keyb_check() ) {
    if (!keyboard_read(&c)) return keyboard_reply(c, leds);
  }
  return 0;
}


int main() {
  //Установим выходы регистра 27HC595 и диодов
  //DDRD = (1 << RDATA_PIN) | (1 << RCLOCK_PIN) | (1 << RLATCH_PIN) | (1 << LED1_PIN) | (1 << LED2_PIN);

  //Установим оба диода в LOW
  //LED1_PORT &= ~(1 << LED1_PIN);
  //LED2_PORT &= ~(1 << LED2_PIN);
  //bool mc = 1;
  unsigned char km;
  //_delay_us(1000);
  init_ps2();
  //Инициализируем пины PS/2
  

  //установим выходы регистра 27HC165
  //DDRB |= (1 << ICLOCK_PIN) | (1 << ILATCH_PIN);
  //DDRB &= ~(1 << IDATA_PIN);


  //Главный бесконечный цикл
  while (1) {

	//Опрос входящих данных с порта PS/2 и проверка байта состояния светодиодов
    if (keyboard_read_check(&leds)) {
      //Если СAPS включен, зажжем светодиод Св1
      //digitalWrite(LED1, leds);
      if (bitRead(leds, 2) == 1) {
        //digitalWrite(LED1, HIGH);
        LED1_PORT |= (1 << LED1_PIN);
      } else {
        //digitalWrite(LED1, LOW);
        LED1_PORT &= ~(1 << LED1_PIN);
      }
    }

    //Цикл опроса регистра 595
    for (byte i = 0; i < 16; i++) {
      //сформируем адрес строки опроса клавиш в 16битном сдвиговом регистре
      uint16_t ww = (uint16_t)1 << i;
      //И запишем его в порт 595
      RLATCH_PORT &= ~(1 << RLATCH_PIN);  //LOW
      shiftOut(RDATA, RCLOCK, MSBFIRST, highByte(ww));
      shiftOut(RDATA, RCLOCK, MSBFIRST, lowByte(ww));
      RLATCH_PORT |= (1 << RLATCH_PIN);  //HIGH

      //Считаем значение с регистра 165
      uint16_t b = shiftIn165();

      //Проверяем по строкам от 0 до 7
      for (byte j = 0; j < CHIP_J_COUNT; j++) {
        if (bitRead(b, j) == 1) {  // Проверяем на нажатие
          if (bitRead(pr[i], j) == 0) { //Если клавиша еще не нажата, то отправим ее код
            //LED1_PORT |= (1 << LED1_PIN);  //HIGH
            km = pgm_read_byte(&keymap[j + 16 * i]);
            //Проверим, не должна ли клавиша сообщать расширенный код
            if (km >= 0xE0) {
              //Если код из таблицы кодов >= E0, то читаем последовательность из массива
              //с номером (Код - E0)
              for (int k = 0; k < EXT_K_SIZE; k++) {
                unsigned char ekm = pgm_read_byte(&extcodes[k + EXT_K_SIZE * (km - 0xE0)]);
                if (ekm > 0x00) {
                  keyb_write(ekm);
                }
              }
            } else {
              //Если не расширенный код, отправляем просто код клавиши
              keyb_write(km);
            }
            bitWrite(pr[i], j, 1);
            LED2_PORT |= (1 << LED2_PIN);
          }
        } else {  //Проверяем на отпускание
          if (bitRead(pr[i], j) == 1) { //Если клавиша была нажата, то, отправим код отпускания
            km = pgm_read_byte(&keymap[j + 16 * i]);
            if (km >= 0xE0) { // По вышеописанному принципу - если код клавиши должен быть расширенным,
              //то выдаем расширенную последовательность из массива extcanscodes
              for (int k = 0; k < EXT_K_SIZE; k++) {
                unsigned char ekm = pgm_read_byte(&extcanscodes[k + EXT_K_SIZE * (km - 0xE0)]);
                if (ekm > 0x00) {
                  keyb_write(ekm);
                  //LED2_PORT &= ~(1 << LED2_PIN);
                }
              }
            } else { // Или выдаем просто один код из массива keymap
              keyb_write(0xF0);
              keyb_write(km);
            }
            bitWrite(pr[i], j, 0);
            LED2_PORT &= ~(1 << LED2_PIN);
          }

        }


      }  //j

    }

    
    
  }  //конец главного цикла

  return 1;
}

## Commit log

2023-08-12 Update ps2-keyb.ino
    Чуть доработано для поддержки нормального ресета по коду, иначе некоторые библиотеки типа FabGL не работали с клавиатурой нормально.
2023-11-15 Iteration 2
    [Butts 2.kicad_sch, keyb.kicad_pcb, keyb.kicad_sch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]
